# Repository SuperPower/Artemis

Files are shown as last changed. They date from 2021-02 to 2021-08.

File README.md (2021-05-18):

# SuperPower
Here you should find the best power supplies for your low-power projects. Because of different requirements for an Raspberry Pi and micro-controllers like the ESP32 we split the project into two boards, one for the Raspberry Pi (SuperPower-Rpi) and one for micro-controllers (SuperPower-uC) with low power.

##### [SuperPower-Rpi](/SuperPower-RPi/) for Raspberry Pi

##### [SuperPower-uC](https://github.com/SuperPower) for micro-controllers and low-power devices

## Licence

All hardware designs and products you can find in this repository is licensed under [CERN Open Hardware Licence Version 2 - Weakly Reciprocal](/LICENCE.txt)

## Relevant links

[Discord Channel](https://discord.gg/dCr86Hk)  

[Google Drive Project Files](https://drive.google.com/drive/folders/1lCirijHUkISdUYBIRblkILHM6fstifWS)

Video (https://www.youtube.com/watch?v=-SJbdPvgQnE "Video")

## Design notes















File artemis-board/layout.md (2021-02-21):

#### Top Layer



#### Bottom Layer



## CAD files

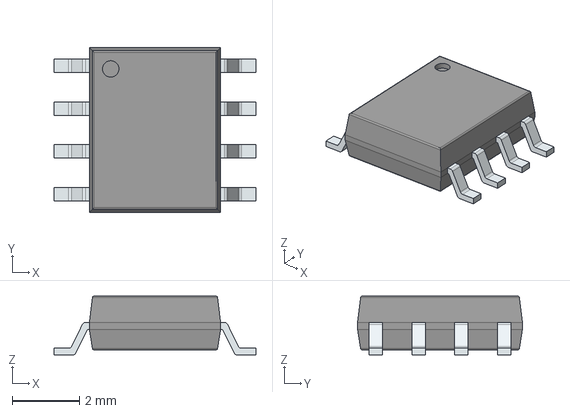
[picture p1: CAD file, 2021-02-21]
components/DMP3028LSD/DMP3028LSD-13.stp
6.00 x 4.90 x 1.75 mm
PinsArrayLR

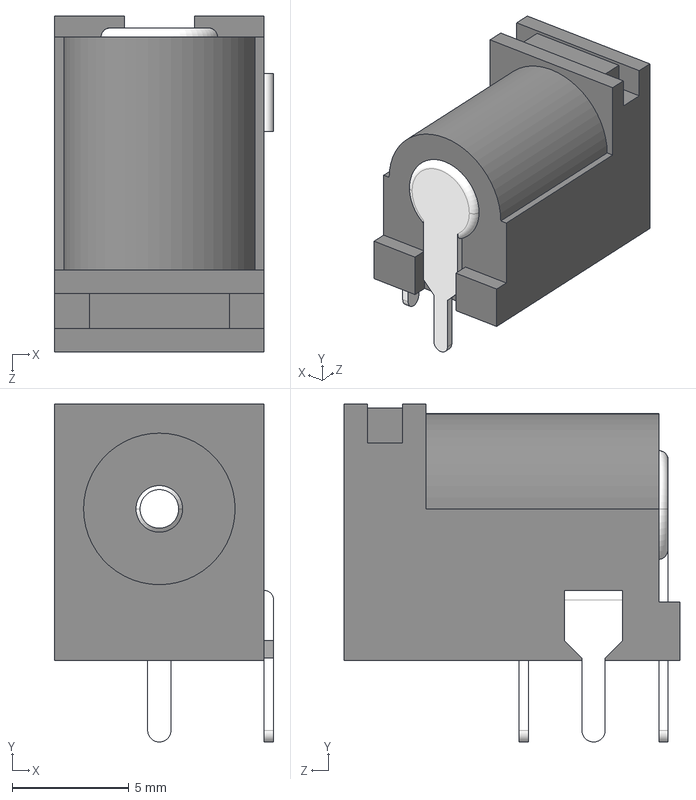
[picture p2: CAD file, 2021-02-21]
components/PJ-102AH--3DModel-STEP-56544.STEP
9.40 x 14.5 x 14.4 mm

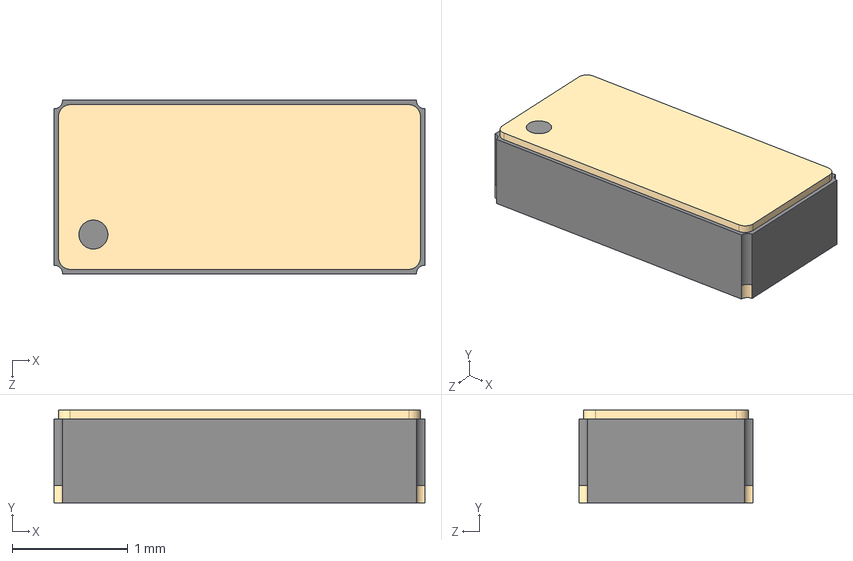
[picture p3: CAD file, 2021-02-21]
components/RV-3028-C7/RV-3028-C7.STEP
3.20 x 0.8 x 1.50 mm

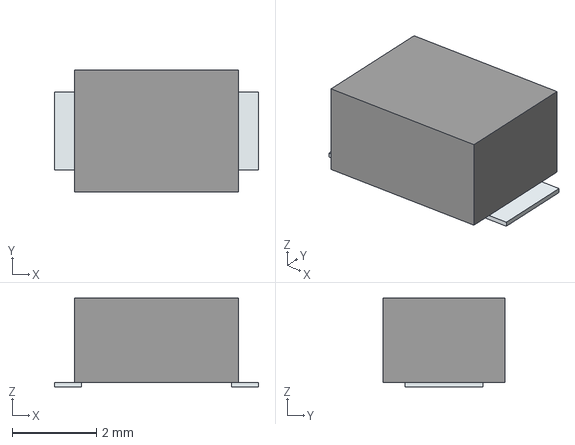
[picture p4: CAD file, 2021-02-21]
components/SKRKAEE020/SKRKAEE020.stp
4.84 x 2.90 x 2.10 mm
Pins

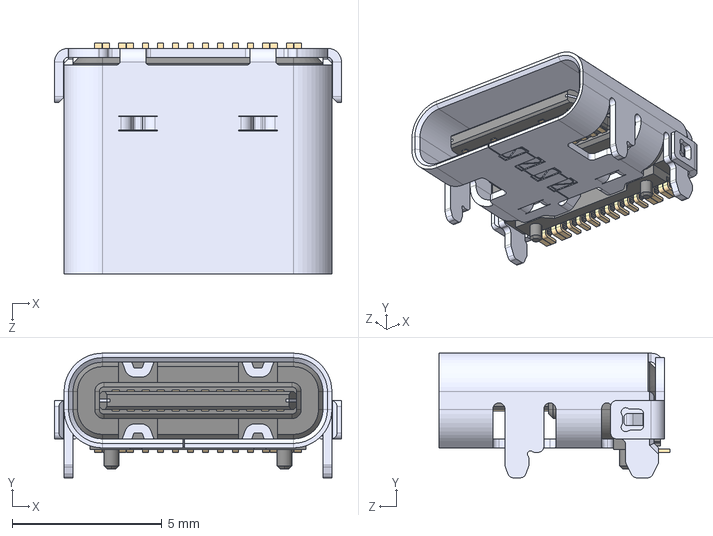
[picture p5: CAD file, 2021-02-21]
components/USB-C/USB4105.STEP
9.58 x 4.16 x 7.71 mm

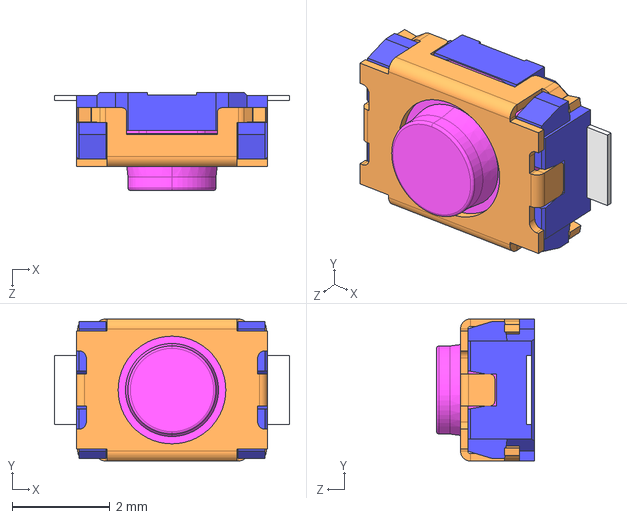
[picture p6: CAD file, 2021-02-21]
components/SKRKAEE020/SKRKAE.STEP
4.80 x 2.90 x 2.00 mm

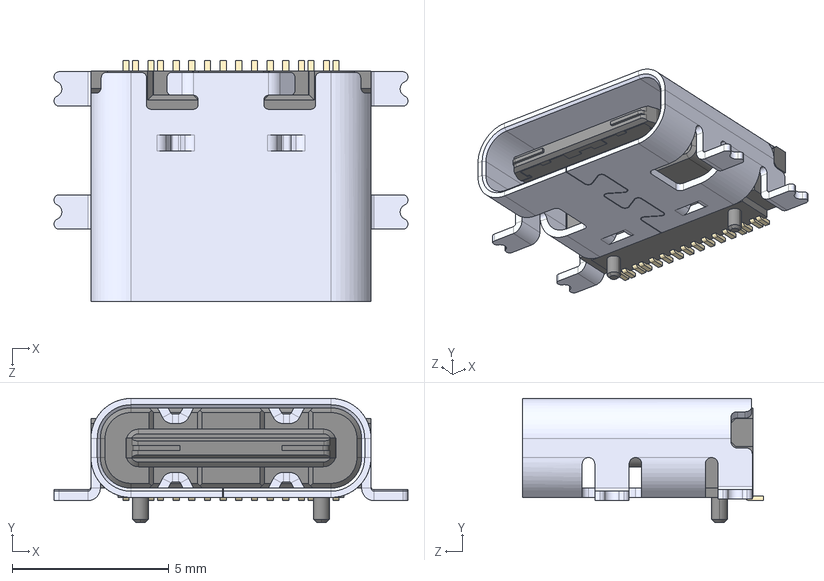
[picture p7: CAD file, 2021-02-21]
components/USB-C/USB4110-GF-A--3DModel-STEP-56544.STEP
11.3 x 3.96 x 7.68 mm

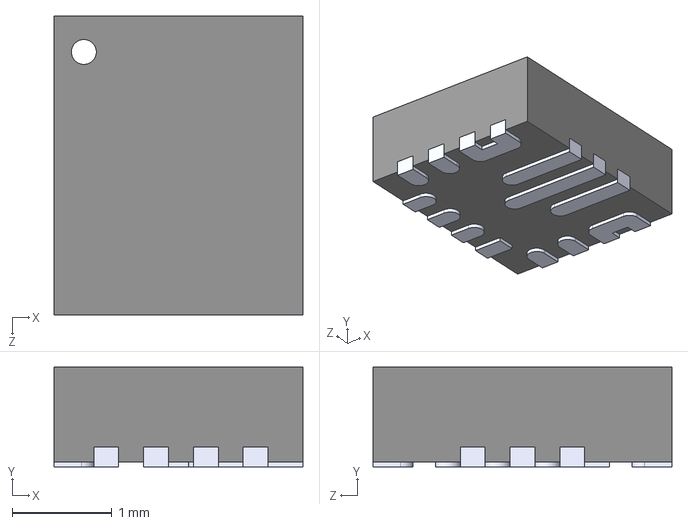
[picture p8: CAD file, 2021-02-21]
components/TPS63070RNM/TPS63070RNMT.STEP
2.50 x 1.00 x 3.00 mm

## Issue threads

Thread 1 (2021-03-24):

library format, content and packaging

wassfila, 2021-03-24:
current code location
https://github.com/SuperPower/Artemis/tree/master/artemis-board/library%20and%20sample%20code

Example library packaging
https://github.com/ESP32Home/ESPNowWrapper

example usage project
https://github.com/ESP32Home/esp32_iot/tree/master/10_esp_now_mqtt_gateway

repo name :
- artemis_library
- apollo_library

# Common lib

in Artemis project
```c++
#include <superpower.h>
superpower board = superpower("artemis");
```

in Apollo project
```c++
#include <superpower.h>
superpower board = superpower("apollo");
```
# Separate lib
Option 1
in Artemis project
```c++
#include <superpower_artemis.h>
artemis board = artemis();
```
Option 2
```c++
#include <superpower_artemis.h>
supoerpower board = superpower();
```

wassfila, 2021-03-24:
sleep_minutes
sleep_seconds

sleep() <255
sleep() 360 =>
sleep() 365 => error_ok, error_time_rounded

Tobi3566, 2021-03-27:
Public methods that could be added:
```c++
void set_int_pulsed(bool type); //enable / disable pulsed signal for timer interrupts
void set_alarm(byte minute); //alarm if minutes ==
void set_alarm(byte minute, byte hour); //alarm for hours & minutes ==
void set_alarm(byte minute, byte hour, byte day, bool weekday); // bool weekday for distinguishing between day of month / day of week
void set_alarm(byte minute, byte hour, byte day, byte weekday); //alarm for hours & minutes & day & weekday ==
void set_charging(bool state); //manually disable charging

```

Informaticore, 2021-04-18:
@Tobi3566 whenever there will be a merge request for the code at some point I will add my 50cents about code there because I can reference line of code directly

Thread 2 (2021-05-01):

prototype findings

Tobi3566, 2021-05-01:
- R15 too small -->5.5V output which is too high (swap with 24k for 5.1V)
-

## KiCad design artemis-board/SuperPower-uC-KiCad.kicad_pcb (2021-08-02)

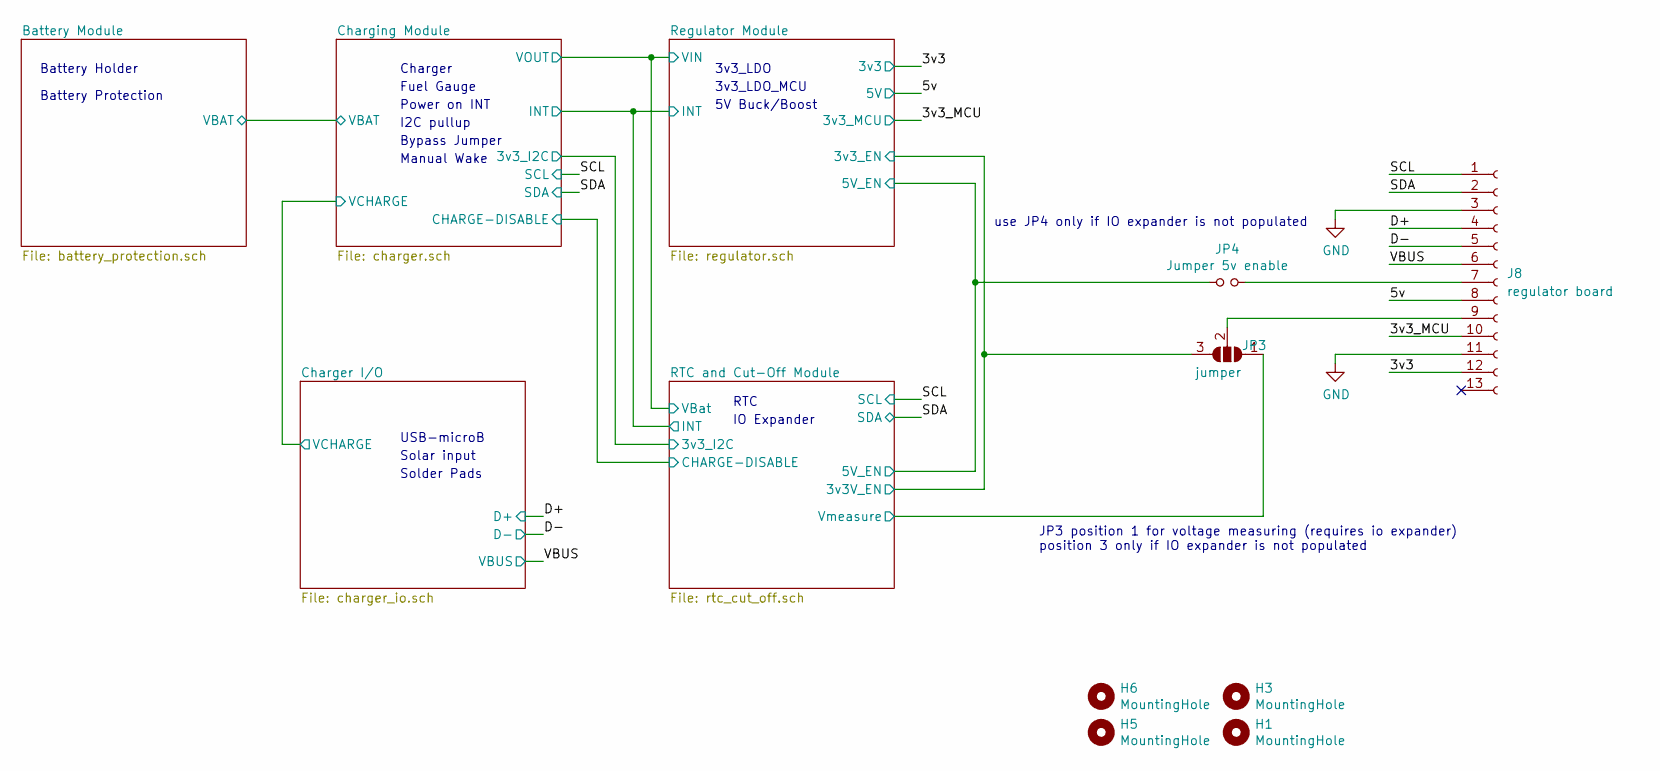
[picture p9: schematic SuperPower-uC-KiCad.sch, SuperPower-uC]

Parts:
H1, H3, H5, H6: MountingHole; MountingHole_2.7mm_M2.5_ISO7380
J8: regulator board; PinSocket_1x13_P2.54mm_Vertical; LCSC C52709
JP3: jumper; SolderJumper-3_P1.3mm_Open_Pad1.0x1.5mm
JP4: Jumper 5v enable; SolderJumper-2_P1.3mm_Open_Pad1.0x1.5mm

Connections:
/3v3: J8.12; also elsewhere on the board
/3v3_MCU: J8.10; also elsewhere on the board
/5v: J8.8; also elsewhere on the board
/D+: J8.4; also elsewhere on the board
/D-: J8.5; also elsewhere on the board
/RTC and Cut-Off Module/3v3V_EN: JP3.3 (B); also elsewhere on the board
/RTC and Cut-Off Module/5V_EN: JP4.1; also elsewhere on the board
/RTC and Cut-Off Module/Vmeasure: JP3.1 (A); also elsewhere on the board
/SCL: J8.1; also elsewhere on the board
/SDA: J8.2; also elsewhere on the board
/VBUS: J8.6; also elsewhere on the board
GND: J8.3, J8.11; also elsewhere on the board
unnamed: J8.7, JP4.2
unnamed: J8.9, JP3.2 (C)

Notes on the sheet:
Battery Holder
Battery Protection
Charger
Fuel Gauge
3v3_LDO
3v3_LDO_MCU
5V Buck/Boost
RTC
USB-microB
Solar input
Solder Pads
Manual Wake
Bypass Jumper
Power on INT
IO Expander
I2C pullup
use JP4 only if IO expander is not populated
JP3 position 1 for voltage measuring (requires io expander) position 3 only if IO expander is not populated

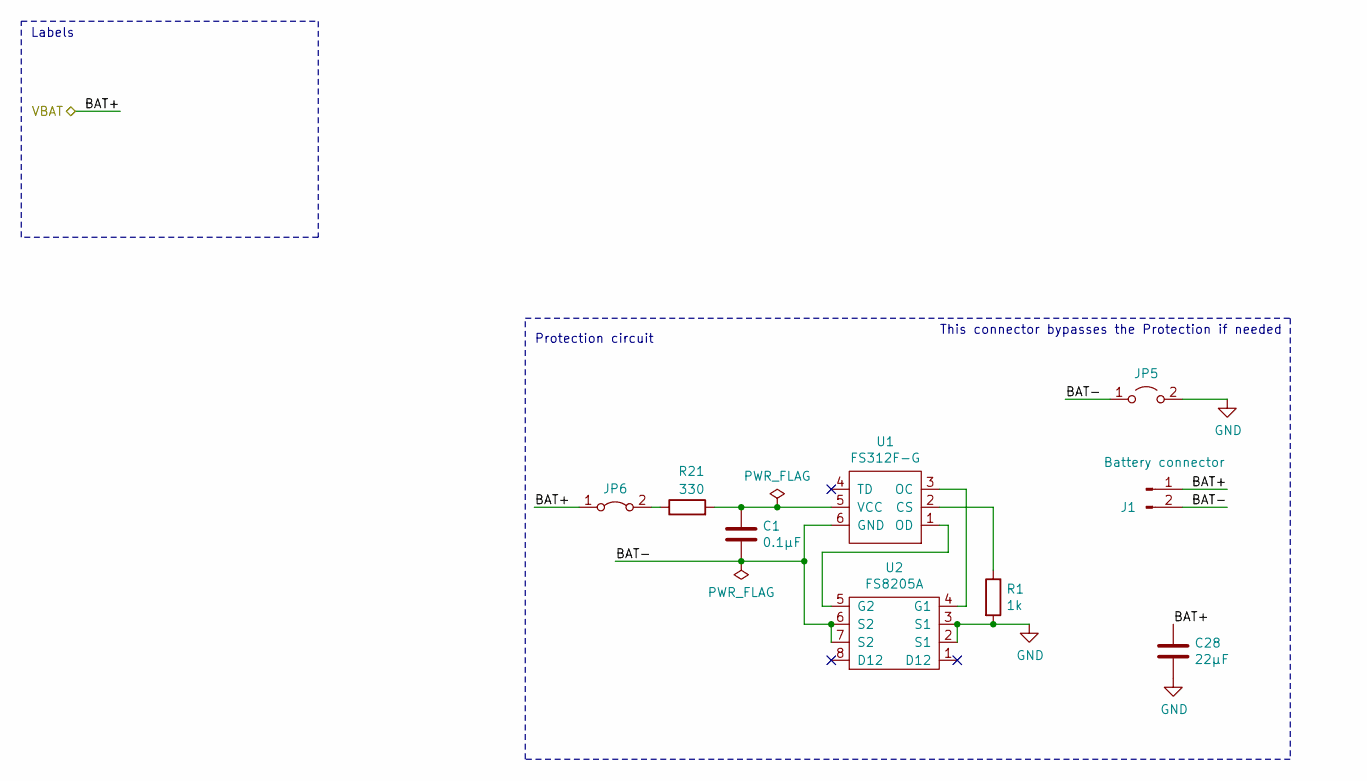
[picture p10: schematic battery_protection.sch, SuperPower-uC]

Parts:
C1: 0.1µF; C_0603_1608Metric_Pad1.05x0.95mm_HandSolder; LCSC C14858
C28: 22µF; C_0805_2012Metric; LCSC C45783
J1: Battery connector; JST_PH_S2B-PH-K_1x02_P2.00mm_Horizontal; LCSC C157932
JP5: Jumper_2_Open; SolderJumper-2_P1.3mm_Open_Pad1.0x1.5mm
JP6: Jumper_2_Bridged; SolderJumper-2_P1.3mm_Bridged_Pad1.0x1.5mm
R1: 1k; R_0603_1608Metric_Pad1.05x0.95mm_HandSolder; LCSC C21190
R21: 330; R_0603_1608Metric_Pad1.05x0.95mm_HandSolder; LCSC C23138
U1: FS312F-G; SOT-23-6; LCSC C82736
U2: FS8205A; TSSOP-8_4.4x3mm_P0.65mm; LCSC C16052

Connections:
/Battery Module/BAT-: C1.2, J1.2, JP5.1 (A), U1.6 (GND), U2.6 (S2), U2.7 (S2)
/Battery Module/VBAT: C28.1, J1.1, JP6.1 (A); also elsewhere on the board
GND: C28.2, JP5.2 (B), R1.2, U2.2 (S1), U2.3 (S1); also elsewhere on the board
unnamed: C1.1, R21.2, U1.5 (VCC)
unnamed: JP6.2 (B), R21.1
unnamed: R1.1, U1.2 (CS)
unnamed: U1.1 (OD), U2.5 (G2)
unnamed: U1.3 (OC), U2.4 (G1)

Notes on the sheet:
Protection circuit
Labels
This connector bypasses the Protection if needed

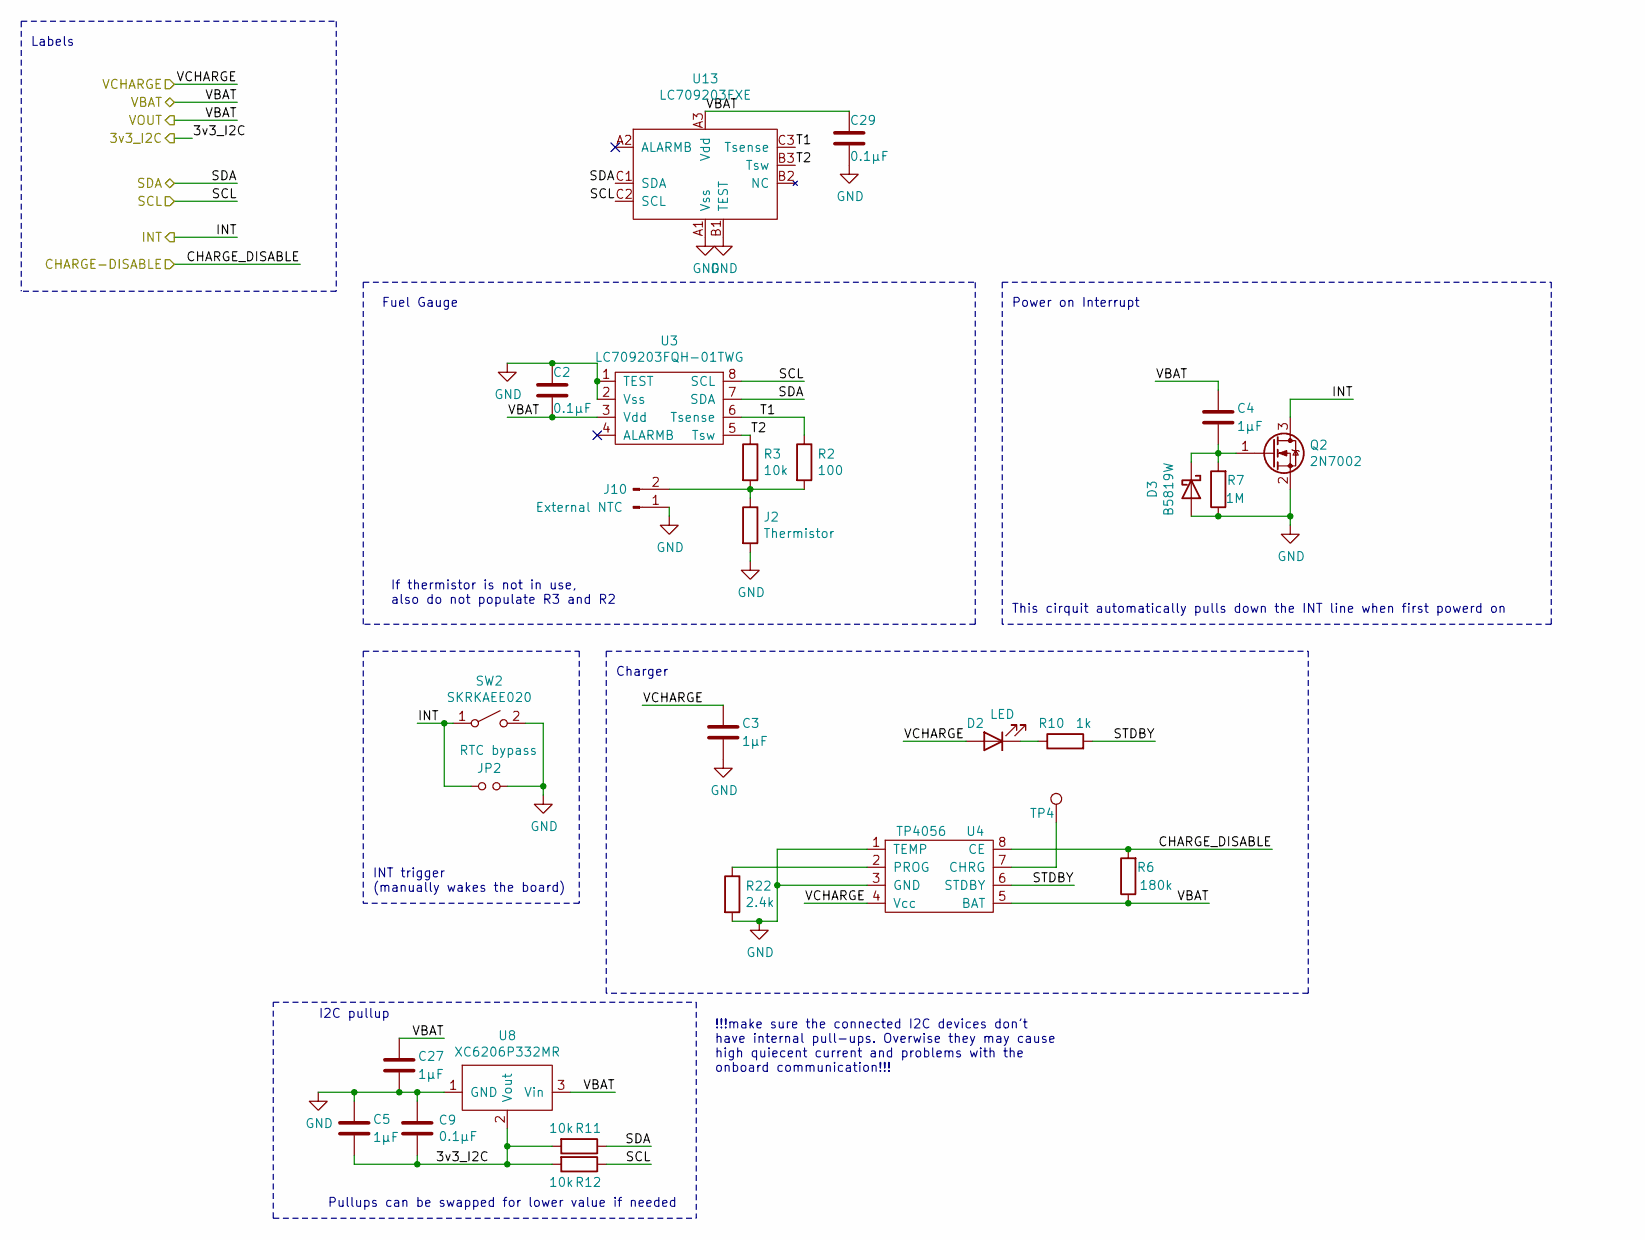
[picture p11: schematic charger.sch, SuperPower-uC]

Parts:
C2, C9, C29: 0.1µF; C_0603_1608Metric_Pad1.05x0.95mm_HandSolder; LCSC C14858
C3, C4, C5, C27: 1µF; C_0603_1608Metric_Pad1.08x0.95mm_HandSolder; LCSC C15849
D2: LED; LED_0603_1608Metric_Pad1.05x0.95mm_HandSolder; LCSC C72041
D3: B5819W; D_SOD-123; LCSC C8598
J2: Thermistor; R_0603_1608Metric_Pad1.05x0.95mm_HandSolder; LCSC C76589
J10: External NTC; PinHeader_1x02_P2.54mm_Vertical
JP2: RTC bypass; PinHeader_1x02_P2.54mm_Vertical
Q2: 2N7002; SOT-23; LCSC C8545
R2: 100; R_0603_1608Metric_Pad1.05x0.95mm_HandSolder; LCSC C22775
R3, R11, R12: 10k; R_0603_1608Metric_Pad1.05x0.95mm_HandSolder; LCSC C25804
R6: 180k; R_0603_1608Metric_Pad1.05x0.95mm_HandSolder; LCSC C22827
R7: 1M; R_0603_1608Metric_Pad0.98x0.95mm_HandSolder; LCSC C22935
R10: 1k; R_0603_1608Metric_Pad1.05x0.95mm_HandSolder; LCSC C21190
R22: 2.4k; R_0603_1608Metric_Pad1.05x0.95mm_HandSolder; LCSC C22940
SW2: SKRKAEE020; SW_Push_SPST_NO_Alps_SKRK; LCSC C115357
TP4: TestPoint; TestPoint_Pad_1.5x1.5mm
U3: LC709203FQH-01TWG; WDFN-8-1EP_4x3mm_P0.65mm_EP2.4x1.8mm; LCSC C152311
U4: TP4056; SOP-8_3.9x4.9mm_P1.27mm; LCSC C16581
U8: XC6206P332MR; SOT-23; LCSC C5446
U13: LC709203FXE; WLCSP-9_3x3_1.76x1.6mm; LCSC C184366

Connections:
/Battery Module/VBAT: C2.2, C4.1, C27.1, C29.1, R6.1, U3.3 (Vdd), U4.5 (BAT), U8.3 (Vin), U13.A3 (Vdd); also elsewhere on the board
/Charger I/O/VCHARGE: C3.1, D2.2 (A), U4.4 (Vcc); also elsewhere on the board
/Charging Module/3v3_I2C: C5.2, C9.2, R11.2, R12.2, U8.2 (Vout); also elsewhere on the board
/Charging Module/CHARGE-DISABLE: R6.2, U4.8 (CE); also elsewhere on the board
/Charging Module/INT: JP2.2, Q2.3 (D), SW2.1 (A); also elsewhere on the board
/Charging Module/STDBY: R10.2, U4.6 (STDBY)
/Charging Module/T1: R2.1, U3.6 (Tsense), U13.C3 (Tsense)
/Charging Module/T2: R3.1, U3.5 (Tsw), U13.B3 (Tsw)
/SCL: R12.1, U3.8 (SCL), U13.C2 (SCL); also elsewhere on the board
/SDA: R11.1, U3.7 (SDA), U13.C1 (SDA); also elsewhere on the board
GND: C2.1, C3.2, C5.1, C9.1, C27.2, C29.2, D3.2 (A), J2.2, J10.1, JP2.1, Q2.2 (S), R7.1, R22.2, SW2.2 (B), U3.1 (TEST), U3.2 (Vss), U4.1 (TEMP), U4.3 (GND), U8.1 (GND), U13.A1 (Vss), U13.B1 (TEST); also elsewhere on the board
unnamed: C4.2, D3.1 (K), Q2.1 (G), R7.2
unnamed: D2.1 (K), R10.1
unnamed: J2.1, J10.2, R2.2, R3.2
unnamed: R22.1, U4.2 (PROG)
unnamed: TP4.1, U4.7 (CHRG)

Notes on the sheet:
Power on Interrupt
Charger
Fuel Gauge
Labels
This cirquit automatically pulls down the INT line when first powerd on
If thermistor is not in use, also do not populate R3 and R2
INT trigger (manually wakes the board)
Pullups can be swapped for lower value if needed
!!!make sure the connected I2C devices don't have internal pull-ups. Overwise they may cause high quiecent current and problems with the onboard communication!!!
I2C pullup

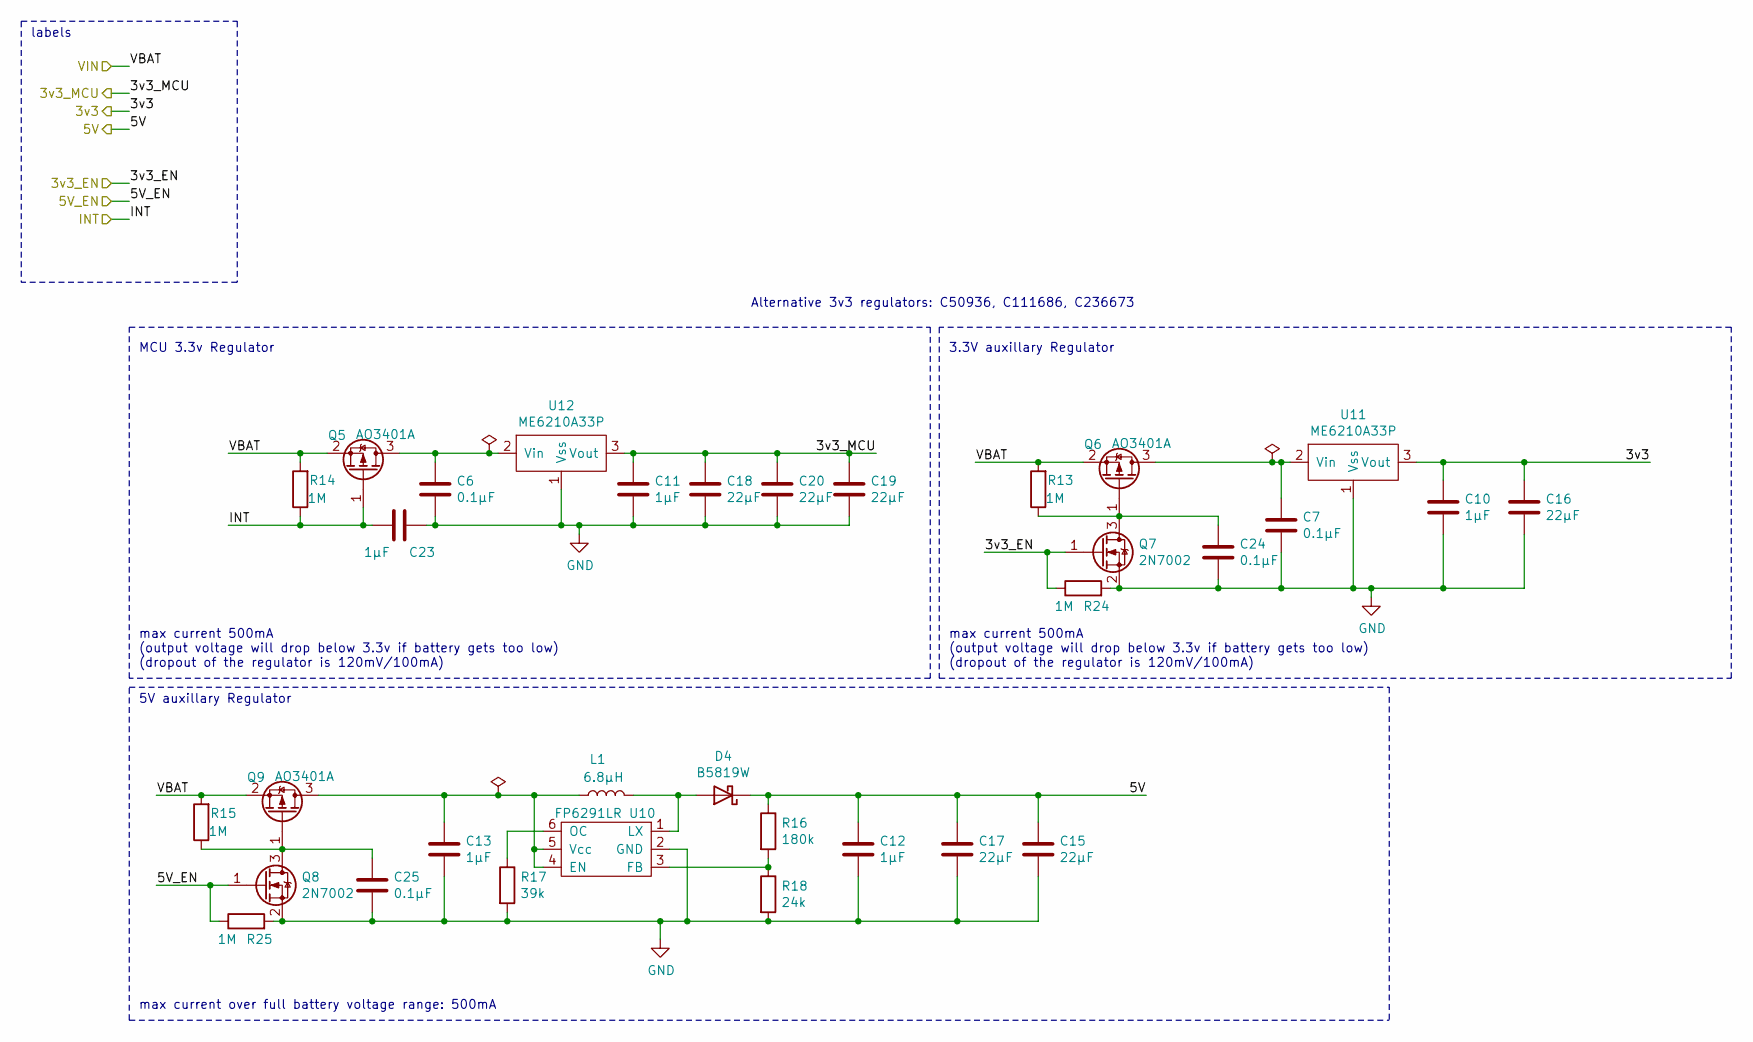
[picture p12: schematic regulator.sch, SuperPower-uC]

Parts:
C6, C7, C24, C25: 0.1µF; C_0603_1608Metric_Pad1.05x0.95mm_HandSolder; LCSC C14858
C10, C11, C12, C13, C23: 1µF; C_0603_1608Metric_Pad1.08x0.95mm_HandSolder; LCSC C15849
C15, C16, C17, C18, C19, C20: 22µF; C_0805_2012Metric; LCSC C45783
D4: B5819W; D_SOD-123; LCSC C8598
L1: 6.8µH; L_Bourns_SRP7028A_7.3x6.6mm; LCSC C207841
Q5, Q6, Q9: AO3401A; SOT-23; LCSC C15127
Q7, Q8: 2N7002; SOT-23; LCSC C8545
R13, R14, R15, R24, R25: 1M; R_0603_1608Metric_Pad0.98x0.95mm_HandSolder; LCSC C22935
R16: 180k; R_0603_1608Metric_Pad1.05x0.95mm_HandSolder; LCSC C22827
R17: 39k; R_0603_1608Metric_Pad1.05x0.95mm_HandSolder; LCSC C23153
R18: 24k; R_0603_1608Metric_Pad1.05x0.95mm_HandSolder; LCSC C23352
U10: FP6291LR; SOT-23-6; LCSC C18701
U11, U12: ME6210A33P; SOT-89-3; LCSC C85233

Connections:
/3v3: C10.1, C16.1, U11.3 (Vout); also elsewhere on the board
/3v3_MCU: C11.1, C18.1, C19.1, C20.1, U12.3 (Vout); also elsewhere on the board
/5v: C12.1, C15.1, C17.1, D4.1 (K), R16.1; also elsewhere on the board
/Battery Module/VBAT: Q5.2 (S), Q6.2 (S), Q9.2 (S), R13.2, R14.2, R15.2; also elsewhere on the board
/Charging Module/INT: C23.2, Q5.1 (G), R14.1; also elsewhere on the board
/RTC and Cut-Off Module/3v3V_EN: Q7.1 (G), R24.1; also elsewhere on the board
/RTC and Cut-Off Module/5V_EN: Q8.1 (G), R25.1; also elsewhere on the board
GND: C6.2, C7.2, C10.2, C11.2, C12.2, C13.2, C15.2, C16.2, C17.2, C18.2, C19.2, C20.2, C23.1, C24.2, C25.2, Q7.2 (S), Q8.2 (S), R17.2, R18.2, R24.2, R25.2, U10.2 (GND), U11.1 (Vss), U12.1 (Vss); also elsewhere on the board
unnamed: C6.1, Q5.3 (D), U12.2 (Vin)
unnamed: C7.1, Q6.3 (D), U11.2 (Vin)
unnamed: C13.1, L1.1, Q9.3 (D), U10.4 (EN), U10.5 (Vcc)
unnamed: C24.1, Q6.1 (G), Q7.3 (D), R13.1
unnamed: C25.1, Q8.3 (D), Q9.1 (G), R15.1
unnamed: D4.2 (A), L1.2, U10.1 (LX)
unnamed: R16.2, R18.1, U10.3 (FB)
unnamed: R17.1, U10.6 (OC)

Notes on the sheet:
MCU 3.3v Regulator
3.3V auxillary Regulator
5V auxillary Regulator
labels
Alternative 3v3 regulators: C50936, C111686, C236673
max current over full battery voltage range: 500mA
max current 500mA (output voltage will drop below 3.3v if battery gets too low) (dropout of the regulator is 120mV/100mA)

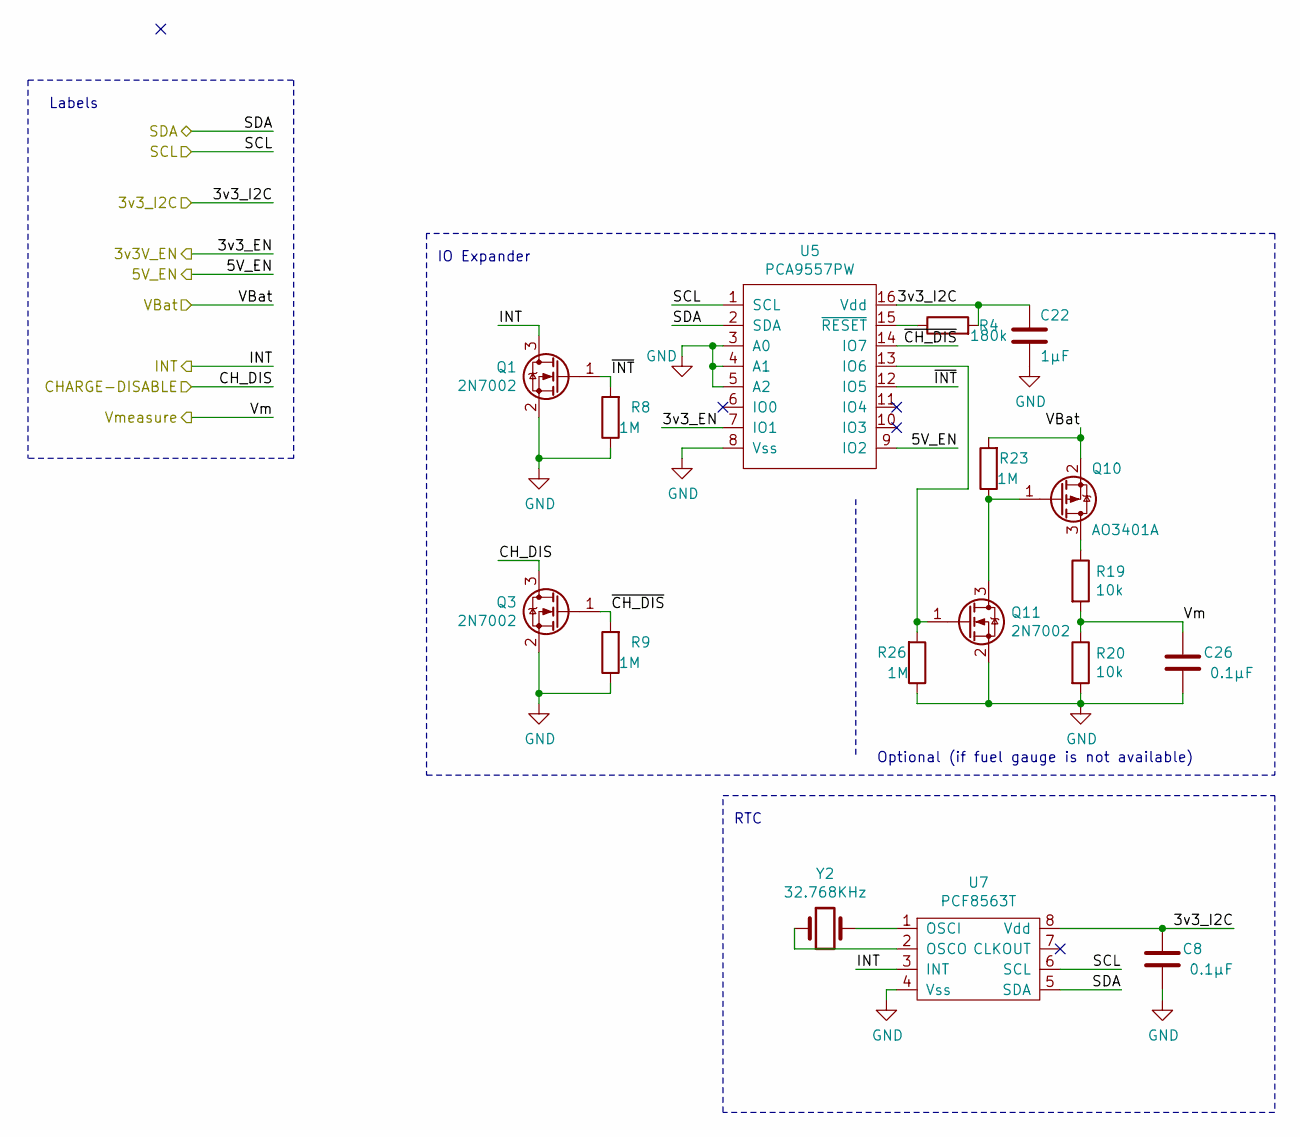
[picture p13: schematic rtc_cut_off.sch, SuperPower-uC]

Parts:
C8, C26: 0.1µF; C_0603_1608Metric_Pad1.05x0.95mm_HandSolder; LCSC C14858
C22: 1µF; C_0603_1608Metric_Pad1.08x0.95mm_HandSolder; LCSC C15849
Q1, Q3, Q11: 2N7002; SOT-23; LCSC C8545
Q10: AO3401A; SOT-23; LCSC C15127
R4: 180k; R_0603_1608Metric_Pad1.05x0.95mm_HandSolder; LCSC C22827
R8, R9, R23, R26: 1M; R_0603_1608Metric_Pad0.98x0.95mm_HandSolder; LCSC C22935
R19, R20: 10k; R_0603_1608Metric_Pad1.05x0.95mm_HandSolder; LCSC C25804
U5: PCA9557PW; TSSOP-16_4.4x5mm_P0.65mm; LCSC C141380
U7: PCF8563T; SOIC-8_3.9x4.9mm_P1.27mm; LCSC C7440
Y2: 32.768KHz; Crystal_SMD_3215-2Pin_3.2x1.5mm; LCSC C32346

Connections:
/Battery Module/VBAT: Q10.2 (S), R23.2; also elsewhere on the board
/Charging Module/3v3_I2C: C8.2, C22.2, R4.2, U5.16 (Vdd), U7.8 (Vdd); also elsewhere on the board
/Charging Module/CHARGE-DISABLE: Q3.3 (D); also elsewhere on the board
/Charging Module/INT: Q1.3 (D), U7.3 (INT); also elsewhere on the board
/RTC and Cut-Off Module/3v3V_EN: U5.7 (IO1); also elsewhere on the board
/RTC and Cut-Off Module/5V_EN: U5.9 (IO2); also elsewhere on the board
/RTC and Cut-Off Module/Vmeasure: C26.2, R19.2, R20.1; also elsewhere on the board
/RTC and Cut-Off Module/~CH_DIS: Q3.1 (G), R9.2, U5.14 (IO7)
/RTC and Cut-Off Module/~INT: Q1.1 (G), R8.2, U5.12 (IO5)
/SCL: U5.1 (SCL), U7.6 (SCL); also elsewhere on the board
/SDA: U5.2 (SDA), U7.5 (SDA); also elsewhere on the board
GND: C8.1, C22.1, C26.1, Q1.2 (S), Q3.2 (S), Q11.2 (S), R8.1, R9.1, R20.2, R26.1, U5.3 (A0), U5.4 (A1), U5.5 (A2), U5.8 (Vss), U7.4 (Vss); also elsewhere on the board
unnamed: Q10.1 (G), Q11.3 (D), R23.1
unnamed: Q10.3 (D), R19.1
unnamed: Q11.1 (G), R26.2, U5.13 (IO6)
unnamed: R4.1, U5.15 (~RESET)
unnamed: U7.1 (OSCI), Y2.2
unnamed: U7.2 (OSCO), Y2.1

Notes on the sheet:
Labels
RTC
IO Expander
Optional (if fuel gauge is not available)

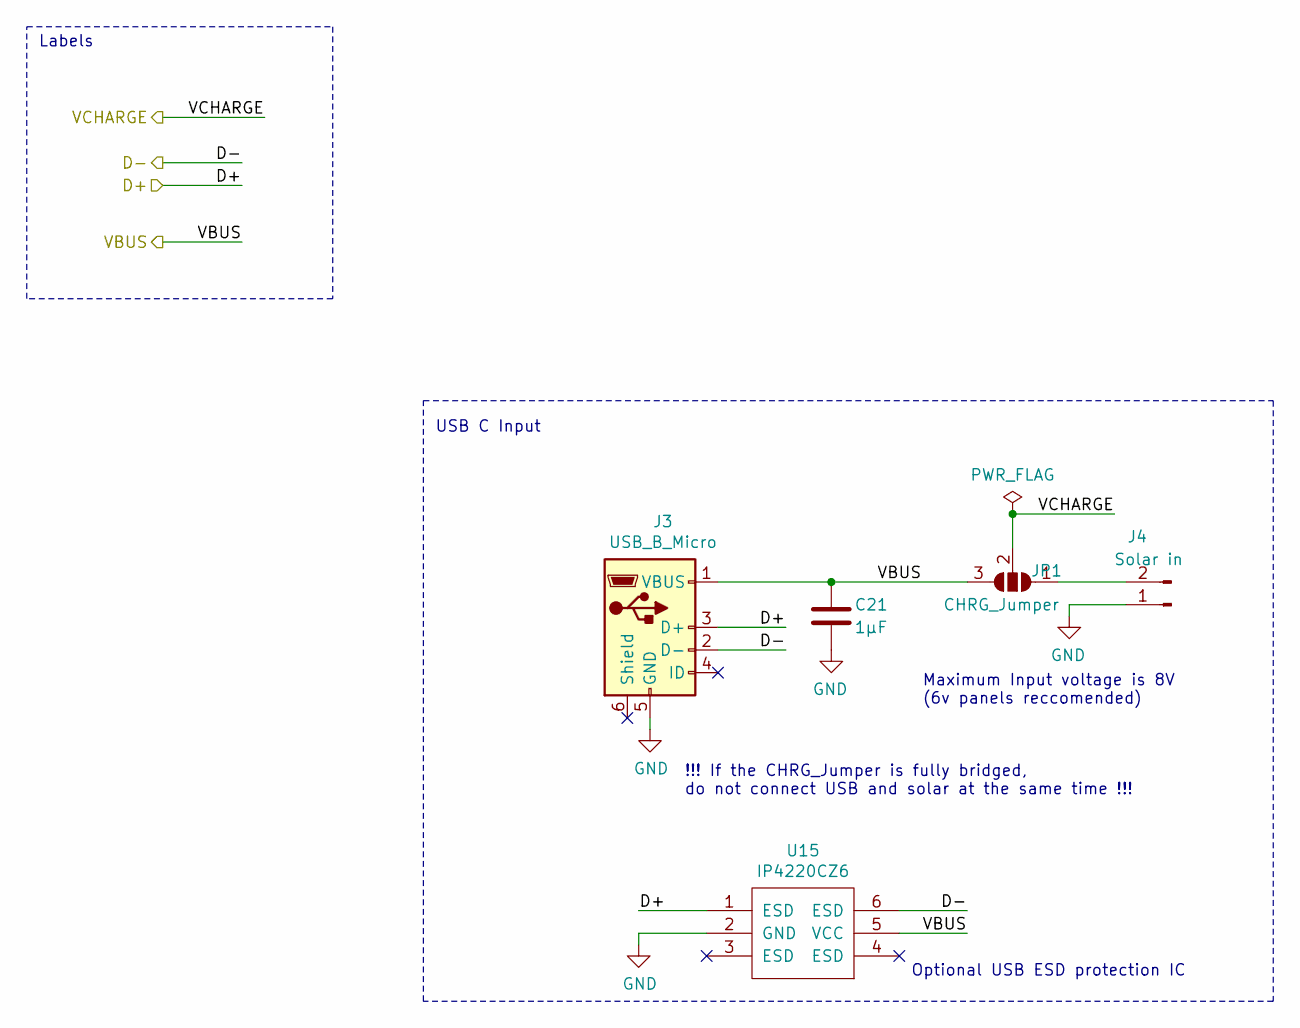
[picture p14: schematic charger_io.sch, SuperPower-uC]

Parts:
C21: 1µF; C_0603_1608Metric_Pad1.08x0.95mm_HandSolder; LCSC C15849
J3: USB_B_Micro; USB_Micro-B_Molex-105017-0001; LCSC C404969
J4: Solar in; JST_EH_S2B-EH_1x02_P2.50mm_Horizontal; LCSC C225424
JP1: CHRG_Jumper; SolderJumper-3_P1.3mm_Open_Pad1.0x1.5mm
U15: IP4220CZ6; TSOP-6_1.65x3.05mm_P0.95mm

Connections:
/Charger I/O/VCHARGE: JP1.2 (C); also elsewhere on the board
/D+: J3.3 (D+), U15.1 (ESD); also elsewhere on the board
/D-: J3.2 (D-), U15.6 (ESD); also elsewhere on the board
/VBUS: C21.1, J3.1 (VBUS), JP1.3 (B), U15.5 (VCC); also elsewhere on the board
GND: C21.2, J3.5 (GND), J4.1, U15.2 (GND); also elsewhere on the board
unnamed: J4.2, JP1.1 (A)

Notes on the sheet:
USB C Input
Labels
Maximum Input voltage is 8V (6v panels reccomended)
!!! If the CHRG_Jumper is fully bridged, do not connect USB and solar at the same time !!!
Optional USB ESD protection IC

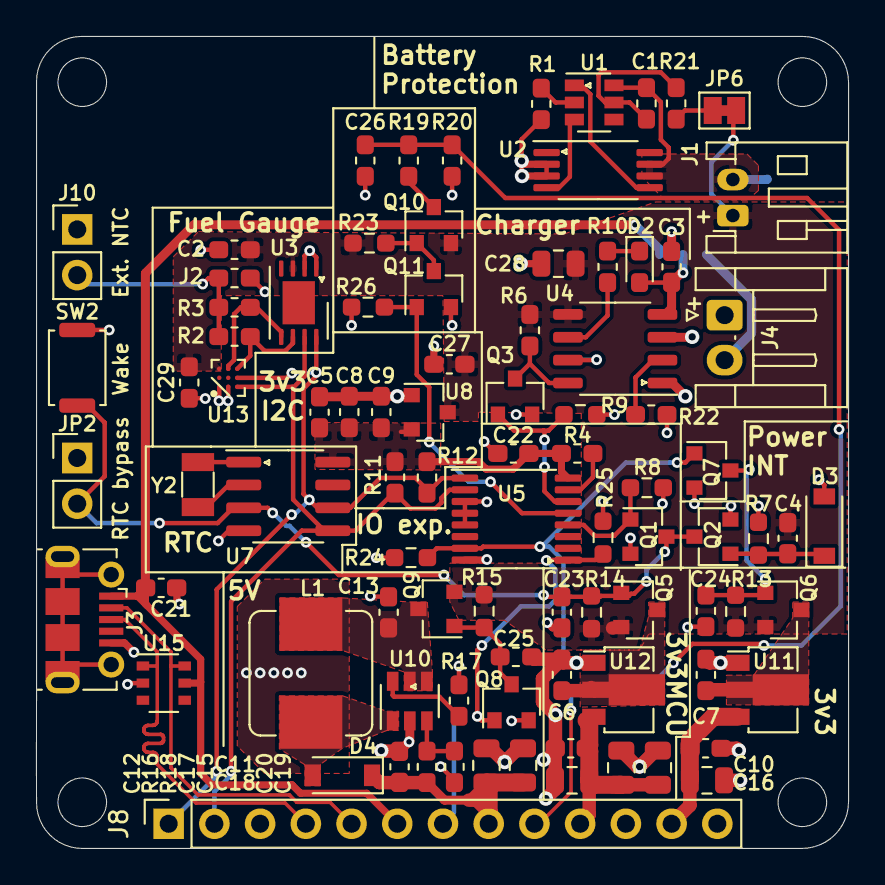
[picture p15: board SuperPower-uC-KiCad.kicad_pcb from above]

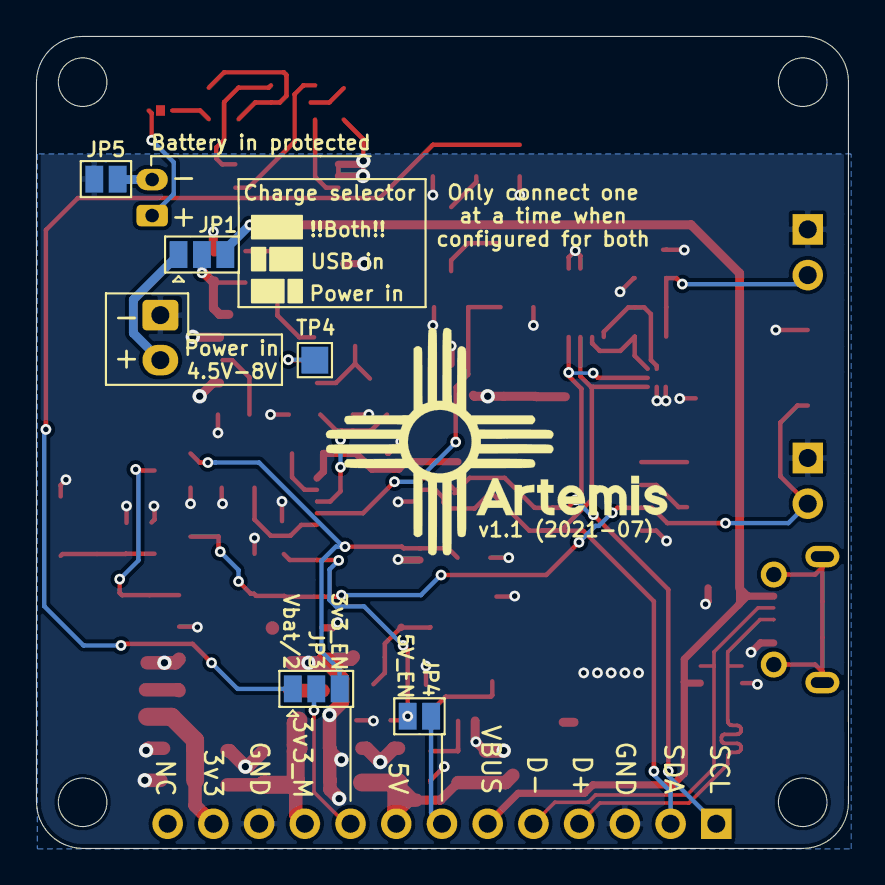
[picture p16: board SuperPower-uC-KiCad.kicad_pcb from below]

Board: 4 copper layers, 45.1 x 45.1 mm, 98 parts (5 on the bottom side), 50 nets.

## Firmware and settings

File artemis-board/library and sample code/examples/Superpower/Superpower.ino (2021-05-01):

#include <superpower.h>
#include <Wire.h>
superpower board = superpower();

void setup() {
  Serial.begin(115200);
  int i = board.init();
  if(i == 0) {
    board.set_time(0, 5, 14, 4, 30, 12, 20);
    Serial.println("configuring");
  }
  else if(i == 1) {
    Serial.println("RTC timer triggered");
  }
  else {
    Serial.println("something else triggered");
  }
  pinMode(2, OUTPUT);
  
}

void loop() {
  //turn on led
  board.set_AUX3(1);
  board.set_AUX5(1);

  for(int i = 0; i < 5; i++) {
    //print out battery status
    Serial.print("Bat Voltage: ");
    Serial.print(board.get_voltage(), 3);
    Serial.println("V");
    
    Serial.print("Bat Charge: ");
    Serial.print(board.get_percentage(), 1);
    Serial.println("%");
    
    Serial.print("Bat Temp: ");
    Serial.print(board.get_temperature(), 1);
    Serial.println("°C");
    digitalWrite(2, HIGH);
    delay(100);
    digitalWrite(2, LOW);
    delay(900);
  }
  
  //print out time
  Serial.print(board.get_second());
  Serial.print(":");
  Serial.print(board.get_minute());
  Serial.print(":");
  Serial.println(board.get_hour());
  Serial.print(board.get_day());
  Serial.print("/");
  Serial.print(board.get_month());
  Serial.print("/20");
  Serial.println(board.get_year());
  Serial.print("Day: ");
  Serial.println(board.get_weekday());

  Serial.print("stamp: ");
  Serial.println(board.get_timestamp());

  //turn off led
  board.set_AUX3(0);
  board.set_AUX5(0);
  board.sleep_seconds(10);
  
  delay(20000);
  while(1){
    Serial.println("something went wrong or waiting for programming");
    delay(10000);
  }
}

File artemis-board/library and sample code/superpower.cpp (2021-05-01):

#include "superpower.h"
#include "Wire.h"

superpower::superpower() {
	a = B00000000;
}

int superpower::init() {
	Wire.begin();
	byte exp_config = wire_RX_8(EXP_addr, EXP_CONFIG);
	if(exp_config == B11111111) {
		wire_TX(EXP_addr, EXP_CONFIG, B00001000);						//set all exept Charge disable to outputs
		set_MCU(true);
		
		wire_TX(FG_addr, FG_POWERMODE, 0x0001 , true);					//sets FG power mode to active
		wire_TX(FG_addr, FG_APA, 0x0036 , true);						//sets battery pack to 3000mah
		wire_TX(FG_addr, FG_BATTPROF, 0x0001 , true);					//sets battery profile to 4.2v
		wire_TX(FG_addr, FG_INITRSOC, 0xAA55 , true);					//init RSOC
		wire_TX(FG_addr, FG_STATUSBIT, 0x0001 , true);					//sets thermistor mode for temperature
		wire_TX(FG_addr, FG_THERMISTORB, 3900 , true);					//sets thermistor sensitivity
		return 0;
	}
	
	set_MCU(true);
	wire_TX(FG_addr, FG_POWERMODE, 0x0001 , true);						//sets FG power mode to active
	if((wire_RX_8(RTC_addr, RTC_CONTROL_2) & B00000100) == B00000100) {
		a = wire_RX_8(RTC_addr, RTC_CONTROL_2) & B11111011;				//resets Timer flag
		wire_TX(RTC_addr, RTC_CONTROL_2, a);
		return 1;
	}
	return 2;
}


void superpower::set_time(byte second, byte minute, byte hour, byte weekday, byte dayofmonth, byte month, byte year) {
	Wire.beginTransmission(RTC_addr);
    Wire.write(RTC_VL_SECOND);
    Wire.write(decToBcd(second));  
    Wire.write(decToBcd(minute));
    Wire.write(decToBcd(hour));     
    Wire.write(decToBcd(weekday));
    Wire.write(decToBcd(dayofmonth));  
    Wire.write(decToBcd(month));
    Wire.write(decToBcd(year));
    Wire.endTransmission();
}

String superpower::get_timestamp() {
	String stamp = "";
	Wire.beginTransmission(RTC_addr);
	Wire.write(RTC_VL_SECOND);
	Wire.endTransmission();
	Wire.requestFrom(RTC_addr, 7);
	int seconds = bcdToDec(Wire.read() & B01111111);					// remove VL error bit
	int minutes = bcdToDec(Wire.read() & B01111111);					// remove unwanted bits from MSB
	stamp += (String)bcdToDec(Wire.read() & B00111111) + ":" + minutes + ":" + seconds + ";"; 
	stamp += (String)bcdToDec(Wire.read() & B00111111) + "/";
	int dayofweek = bcdToDec(Wire.read() & B00000111);
	stamp += (String)bcdToDec(Wire.read() & B00011111) + "/20";			// remove century bit
	stamp += (String)bcdToDec(Wire.read()) + ";";
	stamp += (String)dayofweek;
	return stamp;
}

byte superpower::get_second() {
	return bcdToDec(wire_RX_8(RTC_addr, RTC_VL_SECOND) & B01111111);
}

byte superpower::get_minute() {
	return bcdToDec(wire_RX_8(RTC_addr, RTC_MINUTE) & B01111111);
}

byte superpower::get_hour() {
	return bcdToDec(wire_RX_8(RTC_addr, RTC_HOUR) & B00111111);
}

byte superpower::get_weekday() {
	return bcdToDec(wire_RX_8(RTC_addr, RTC_Weekday) & B00000111);
}

byte superpower::get_day() {
	return bcdToDec(wire_RX_8(RTC_addr, RTC_DAY) & B00111111);
}

byte superpower::get_month() {
	return bcdToDec(wire_RX_8(RTC_addr, RTC_MONTH) & B00011111);
}

byte superpower::get_year() {
	return bcdToDec(wire_RX_8(RTC_addr, RTC_YEAR));
}


double superpower::get_temperature() {
	return (double)map(wire_RX_16(FG_addr, FG_CELLTEMPERATURE), 0x9E4, 0xD04, -200, 600) / 10;
}

double superpower::get_voltage() {
	return ((double)wire_RX_16(FG_addr, FG_CELLVOLTAGE)) / 1000;
}

double superpower::get_percentage() {
	return ((double)wire_RX_16(FG_addr, FG_CELLITE)) / 10;
}


void superpower::sleep_minutes(byte minutes) {
	wire_TX(RTC_addr, RTC_CONTROL_2, B00000001);				//activate TIE and clear TF
	wire_TX(RTC_addr, RTC_TIMER_C, B00000011);					//disables timer
	wire_TX(RTC_addr, RTC_TIMER, minutes);						//set timer value
	wire_TX(RTC_addr, RTC_TIMER_C, B10000011);					//enable timer with 1/60HZ

	wire_TX(FG_addr, FG_POWERMODE, 0x0002, true);				//sets FG power mode to sleep
	set_MCU(false);                    							//mcu regulator off
}

void superpower::sleep_seconds(byte seconds) {
	wire_TX(RTC_addr, RTC_CONTROL_2, B00000001);				//activate TIE and clear TF
	wire_TX(RTC_addr, RTC_TIMER_C, B00000011);					//disables timer
	wire_TX(RTC_addr, RTC_TIMER, seconds);						//set timer value
	wire_TX(RTC_addr, RTC_TIMER_C, B10000010);					//enable timer with 1HZ
	
	wire_TX(FG_addr, FG_POWERMODE, 0x0002, true);				//sets FG power mode to sleep
	set_MCU(false);  
}


void superpower::set_AUX3(bool state) {
	set_EXP(1, state);
}

void superpower::set_AUX5(bool state) {
	set_EXP(2, state);
}

bool superpower::get_EXP(byte pin) {
	return wire_RX_8(EXP_addr, EXP_INPUT) & (B00000001 << pin);
}

void superpower::set_EXP(byte pin, bool state) {
	if(!state) {
		a = wire_RX_8(EXP_addr, EXP_OUTPUT) & (B11111111 - (B00000001 << pin));
	}
	else {
		a = wire_RX_8(EXP_addr, EXP_OUTPUT) | (B00000001 << pin);
	}
	wire_TX(EXP_addr, EXP_OUTPUT, a);
}

void superpower::config_EXP(byte pin, bool type) {
	if(type) {
		a = wire_RX_8(EXP_addr, EXP_CONFIG) & (B11111111 - (B00000001 << pin));
	}
	else {
		a = wire_RX_8(EXP_addr, EXP_CONFIG) | (B00000001 << pin);
	}
	wire_TX(EXP_addr, EXP_CONFIG, a);
}

///////////////////////////////////Private Functions//////////////////////////////////////

void superpower::set_MCU(bool state) {
	set_EXP(0, state);
}


byte superpower::decToBcd(byte value) {
	return (value / 10 * 16 + value % 10);
}

byte superpower::bcdToDec(byte value) {
	return ((value / 16) * 10 + value % 16);
}

uint8_t superpower::crc8(uint8_t *data, int len) {
	const uint8_t POLYNOMIAL(0x07);
	uint8_t crc(0x00);
	for (int j = len; j; --j) {
		crc ^= *data++;
		for (int i = 8; i; --i) {
			crc = (crc & 0x80) ? (crc << 1) ^ POLYNOMIAL : (crc << 1);
		}
	}
	return crc;
}


uint8_t superpower::wire_TX(uint8_t address, uint8_t command, uint16_t msg, bool crc) {
	uint8_t dat[5];
	dat[0] = address * 2;
	dat[1] = command;
	dat[2] = msg & 0xFF;
	dat[3] = msg >> 8;
	dat[4] = crc8(dat, 4);
	Wire.beginTransmission(address);
	Wire.write(dat[1]);
	Wire.write(dat[2]);
	Wire.write(dat[3]);
	Wire.write(dat[4]);
	uint8_t i = Wire.endTransmission();
	return i;
}

uint8_t superpower::wire_TX(uint8_t address, uint8_t command, uint8_t msg) {
	Wire.beginTransmission(address);
	Wire.write(command);
	Wire.write(msg);
	uint8_t i = Wire.endTransmission();
	return i;
}

uint16_t superpower::wire_RX_16(uint8_t address, uint8_t command) {
	uint16_t dat;
	uint8_t reply[3];
	Wire.beginTransmission(address);
	Wire.write(command);
	Wire.endTransmission(false);
	Wire.requestFrom(address, 3);
	reply[0] = Wire.read();
	reply[1] = Wire.read();
	reply[2] = Wire.read();
	dat = reply[1];
	dat <<= 8;
	dat |= reply[0];
	return dat;
}

uint8_t superpower::wire_RX_8(uint8_t address,  uint8_t command) {
	Wire.beginTransmission(address);
	Wire.write(command);
	Wire.endTransmission();
	Wire.requestFrom(address, 1);
	return Wire.read();
}

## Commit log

2021-02-21 Move Repo and reduce project files to only contain the Artemis Board
    [BOM.xlsx, DMP3028LSD-13.stp, PJ-102AH--3DModel-STEP-56544.STEP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]
2021-02-22 renamed net lables, disconnected en lines from header and deleted unused
    [SuperPower-uC-KiCad.kicad_pcb, SuperPower-uC-KiCad.sch, mcu.sch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]
2021-02-24 increased output caps of voltage regulators
    [SuperPower-uC-KiCad.kicad_pcb, regulator.sch]
2021-02-25 added library and sample code
2021-02-26 fixed silk placements
    [SuperPower-uC-KiCad.kicad_pcb]
2021-03-05 re-add logo
    [SuperPower-uC-KiCad.kicad_pcb]
2021-03-05 added part number for button
    [charger.sch]
2021-03-08 fixed erc
    [charger_io.sch, rtc_cut_off.sch]
2021-03-08 changed switch value
    [charger.sch]
2021-03-27 connected io expanders Vccp pin to Vbat instead of Vcc_I2c
    [SuperPower-uC-KiCad.kicad_pcb, SuperPower-uC-KiCad.sch, rtc_cut_off.sch]
2021-04-09 moved fuel gauge pin 1 marker to pin 1
    [SuperPower-uC-KiCad.kicad_pcb]
2021-04-29 deleted unused lines in sample code
2021-05-01 fixed brackets in time get functions
    [Superpower.ino, superpower.cpp]
2021-05-15 swapped R15 for 24k
    [regulator.sch]
2021-05-15 added pulldown to Q1 and inverter to CH_DIS
    [rtc_cut_off.sch]
2021-05-15 added cirquit to measure Vbat with esp in case of fuel gauge shortage
    [SuperPower-uC-KiCad.sch, regulator.sch, rtc_cut_off.sch]
2021-05-15 annotated Q10
    [rtc_cut_off.sch]
2021-05-15 applied changes to board
    [SuperPower-uC-KiCad.kicad_pcb, charger.sch, rtc_cut_off.sch]
2021-05-17 removed unused net label
    [SuperPower-uC-KiCad.sch, battery_protection.sch, charger.sch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]
2021-05-19 swapped protection ic for the FS312F-G
    [battery_protection.sch]
2021-05-21 updated revision number
    [SuperPower-uC-KiCad.kicad_pcb]
2021-05-24 added comment with alternative 3v3 regulators
    [regulator.sch]
2021-05-24 swapped switch for cheaper alps one
    [charger.sch]
2021-05-25 changed the layout a bit and removed TP on boost converter
    [SuperPower-uC-KiCad.kicad_pcb, regulator.sch]
2021-05-25 increased value of R17 to decrease 5v overcurrent protection
    [regulator.sch]
2021-05-25 corrected inductor value text field
    [regulator.sch]
2021-05-28 moved Vbat/2 line to other pin on the header
    [SuperPower-uC-KiCad.kicad_pcb, SuperPower-uC-KiCad.sch]
2021-05-30 moved R8 and did some minor silk and routing changes
    [SuperPower-uC-KiCad.kicad_pcb, charger_io.sch]
2021-05-31 added comments and swapped polarity of Vin connector
    [SuperPower-uC-KiCad.kicad_pcb, charger.sch, charger_io.sch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]
2021-06-01 added 1µ cap close to 3v3 I2C regulator
    [SuperPower-uC-KiCad.kicad_pcb, charger.sch]
2021-06-06 swapped and added some lcsc part numbers and DNP markers
    [SuperPower-uC-KiCad.kicad_pcb, SuperPower-uC-KiCad.sch, battery_protection.sch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]
2021-06-07 added cap to Vbat rail for more stability
    [SuperPower-uC-KiCad.kicad_pcb, battery_protection.sch]
2021-06-20 fixed silk being moved on some caps
    [SuperPower-uC-KiCad.kicad_pcb]
2021-06-24 added jumpers for use without io expander
    [SuperPower-uC-KiCad.kicad_pcb, SuperPower-uC-KiCad.sch, regulator.sch]
2021-06-24 added comments for the jumpers and pulldowns for Q7 and Q8
    [SuperPower-uC-KiCad.sch]
2021-07-05 added warning comment for expander ic
    [rtc_cut_off.sch]
2021-07-07 connected VccP of io expander back to 3v3, changed some footprint
    also added NMos so voltage divider can be used
    [SuperPower-uC-KiCad.kicad_pcb, charger.sch, regulator.sch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]
2021-07-09 removed unprotected connector, added jumper, moved cap to 3v3_mcu
    [SuperPower-uC-KiCad.kicad_pcb, battery_protection.sch, regulator.sch]
2021-07-11 added cap to 3v3 I2c, swapped some footprints to normal...
    [SuperPower-uC-KiCad.kicad_pcb, SuperPower-uC-KiCad.sch, battery_protection.sch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]
2021-07-12 removed voltage level warning for io expander due to Vccp on 3v3
    [rtc_cut_off.sch]
2021-07-12 improved silk placement and routing
    [SuperPower-uC-KiCad.kicad_pcb]
2021-07-15 added PCA9557 and swapped IO expander for it
    [SuperPower-uC-KiCad.kicad_pcb, rtc_cut_off.sch]
2021-08-01 added WLCSP9 footprint for LC709203
    [SuperPower-uC-KiCad.kicad_pcb, charger.sch]
2021-08-02 added datasheet for pca9557 and connected ~INT to another pin
    [SuperPower-uC-KiCad.kicad_pcb, rtc_cut_off.sch]

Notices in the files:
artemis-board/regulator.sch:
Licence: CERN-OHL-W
